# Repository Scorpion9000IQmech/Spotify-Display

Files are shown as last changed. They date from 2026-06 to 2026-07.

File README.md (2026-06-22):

## Spotify Display
---
I made a spotify display case, it does a number of things, it is recharchable by a battery module(it is connected to a TP4056 charging module with 3.3V output for the esp32), it has holes for both uploading the code as well as charging the battery

### Display
#### Startup
on startup is shows an animation of a red heart thumping, the text "Manis Music" and "by ahmed" on the screen in green, this lasts for 8 second I beleive
it switches to a loading... screen
#### Main screen
THE MAIN SCREEN shows up which has the pakistan flag on the top right
it has the artist name and track in text that cycles through rainbow colours every 1 second, and the text also has a shadow
there is a progress bar as well the minutes and second below it of how much of the song is complete
there is also a volume bar which changes by increments of 5, starting at 50 percent on startup, this can be contorlled by the volume up and down buttons(this changes the spotify volume, does not work on mobile spotify, only desktop)
the case as a whole has 5 buttons: next, play/pause, previous, Vol up, vol down
#### The Case layout
the screen is in the front of the case, the case has a lid at the back that can be latched on and off.
inside the case there is a space for the screen, screw holes to latch it on, as well as a place for the ESP32 which also has holes to latch it on with a bolt or screw, there is a space for the USB C charging module as well as the battery securing spot.
I also have spots for the keyswitches to sit securely

### Example Images
---






### wiring diagram
---


this is the final, with the space for for all componets to sit securely in the case, and for it to securely close, as well as a heart in which an led will glow, preferrably red!!!

### IM GOING TO PAY FOR THIS ALL MYSELF

## BOM

| **DISPLAYparts** | **cost USD** | **where to get from/link** | 
|---|---|---|
| 3d printer parts | 133 g(diff filaments diff cost but about 1.8 USD) | I get my filament from microless and print with my personal printer |
| Keyboard switches(better reliability) | 7 USD(pakistan local online shop/I suggest getting from another for obvious reasons) | [Daraz Pakistan](https://www.daraz.pk/products/mechanical-keyboard-switches-3-pin-rgb-hot-swappable-blue-red-brown-black-silent-tactile-switches-for-gaming-keyboard-70-million-clicks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) |
| ST7735 SPI | 4.29 USD | [Ali Express](https://ar.aliexpress.com/item/1005010340668858.html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) |
| C3 MINI LOLIN | 14.36 USD | [Ali Express](https://ar.aliexpress.com/item/1005004740051202.html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) |
| BATTERY 3.7V LiPo rechargeable | 2 for 3.9 USD each | (local) |
| TP4056 with protection(MIcro usb-c) | USD 2.32 | [Ali Express](https://ar.aliexpress.com/item/1005007355163444.html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) |
| 6 M3 screws for the screen|depends on your local source | Local bought |
| multimeter to adjust boost converter | 13 USD,(local) | - |
| **TOTAL cost(just the case and componets)** | **40 USD** | - |

# Step by step tutorial/explanation
---
1. upload the code to the esp32, and fill in the internet information, client information from spotify, and the refresh token that you can create, here(https://spotify-refresh-token-generator.netlify.app/#info)
2. solder header pins to the esp32 and the display board, solder the battery to the mt3608 charger module
3. connect the esp32 and display with dupont wires
4. connect the mt3608 to the LED/VCC from display and the 3v3 pin on esp32, this needs to be solered together into a bus, as its 3 wires for one connection, I personally soldered them all to one wire and used that wire to connect to the mt3608 VOUT+
5. use the dupont wires with pins on the other end to connect to the button pins on the esp32, solder the pin end to one end of the key, solder a normal wire with two pins to the other end, as this will be the ground
6. at this point everything is connected if youve gone by the wiring diagram, the code uploaded, and once all the ground wires are connected into one bus, and connected to mt3608 VOUT-, then the display should power on, from here it plays the animation, and displays the song playing, buttons are in the order you arranged them.

# FINAL EXAMPLE IMAGES
---
### the esp32, tp4056 and battery are shown here below all of the messy wiring


### the front showing the display, and what it is displaying


this shows the artist, song, progress of song, and the volume percent, once paused it stops the progress, volume bar changes with the press of the buttons, and it switches every refresh when a new song is played, with previous or next buttons

### the door


the door obviously has space for the two usb ports to work

### the keyswitches on top


all 6 keyswitches, play/pause on the bottom right, next middle bottom, previous is bottom left, vol down button on the top right, and vol up button on the top left, of course the orientation of these changes depending on which pin the wire connected is in each keyslot, but the upper middle button does nothing as of now, it is meant to be for an extra purpose, such as on/off, or to toggle the led which can be kept in the heart, additionallyt if put between the power bus or GND bus, it can be used to restart the display, rerunning the animation, thats what it does for me as of now, a reset button

### the esp32, tp4056 and battery meant to be used




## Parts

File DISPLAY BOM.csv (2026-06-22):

DISPLAYparts | cost USD | where to get from/link
3d printer parts | 133 g(diff filaments diff cost but about 1.8 USD) | I get my filament from microless and print with my personal printer
Keyboard switches(better reliability) | 7 USD(pakistan local online shop/I suggest getting from another for obvious reasons) | https://www.daraz.pk/products/mechanical-keyboard-switches-3-pin-rgb-hot-swappable-blue-red-brown-black-silent-tactile-switches-for-gaming-keyboard-70-million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
ST7735 SPI | 4.29 USD | https://ar.aliexpress.com/item/1005010340668858.html
C3 MINI LOLIN | 14.36 USD | https://ar.aliexpress.com/item/1005004740051202.html
BATTERY 3.7V LiPo rechargeable | 2 for 3.9 USD each | (local)
TP4056 with protection(MIcro usb-c) | USD 2.32 | https://ar.aliexpress.com/item/1005007355163444.html
6 M3 screws for the screen | depends on your local source | Local bought
multimeter to adjust boost converter | 13 USD | (local)

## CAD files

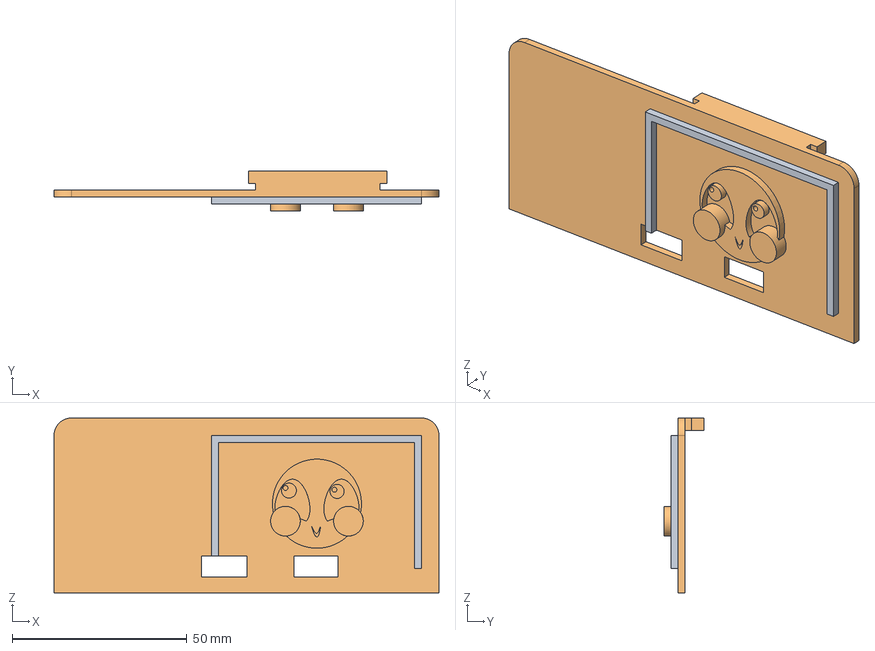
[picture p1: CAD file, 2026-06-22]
STEP files/SPOTIFY DISPLAY 3d print(redesign with keyswitches)(door).step
110.0 x 11.5 x 50.0 mm

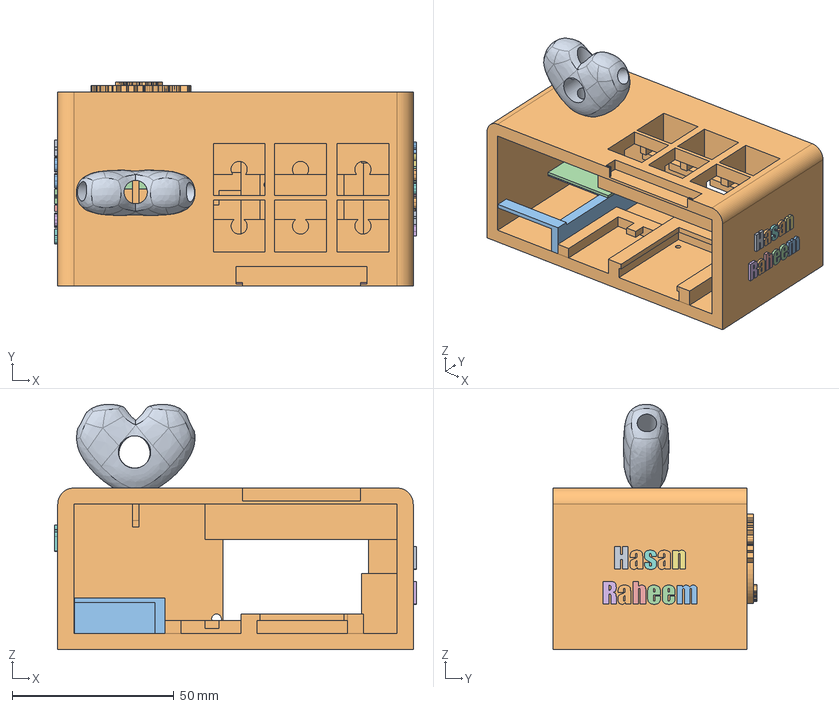
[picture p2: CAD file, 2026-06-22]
STEP files/SPOTIFY DISPLAY 3d print(redesign with keyswitches)(case).step
112.0 x 63.0 x 75.9 mm

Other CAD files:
STEP files/old design, with componets, for the sake of showing where they are placed(ignore the MT3608, it is removed as it wasnt needed).step
STL files/SPOTIFY DISPLAY 3d print(redesign with keyswitches)(case).stl
STL files/SPOTIFY DISPLAY 3d print(redesign with keyswitches)(door).stl

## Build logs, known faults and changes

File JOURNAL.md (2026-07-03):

<!--
  This journal is auto generated by Stasis.
-->

# 6/22/2026 1 PM - Soldered, everything

_Time spent: 7h_

since everythign else was settled, the code working, the keyswtiches soldered, I soldered header pins to the esp32, broke one, resoldered another esp32, used the same pins, connected the keyswtiches to new pins(soldered), as the last ones woudnt connect to the header pins

I then soldered all the GND wires together and connected that mess to the VOUT- of the battery charger module

after that I slid all of it in from the display slot, as the display sits snug in its place, perhaps with the screw holes even better, but it was the only way to get the display in, I put the battery, charger module and esp32 in their places, and then skipped on the booster module entirely as i realized i didnt NEED it, as it worked just fine at 3.3V and it would just add more unncessart wiring


I do not need more wiring, I taped up all the exposed joints as well, just in case
here is the front





here is the door to push all that messy wiring in



here is the esp32 with pinheaders



here is the charger module


the battery


and the keyswitches soldered in









# 6/16/2026 12 PM - Soldered the keyswitched to some wired, tested them out

_Time spent: 1h_

I tested out wether the buttons work, after soldering them to wires, I then tested them out on esp32 and spotify, the next, prev and play/pause button work, but my volume buttons dont actually change the volume yet so im still working on that, as for everything else, its basically done, just need to solder the board to the display, and the buttons as well as the battery





# 6/7/2026 10 AM - I printed and found some problems to redesign and print

_Time spent: 7h_

I first let it print for AGES, but now its done, first of all the front of the print didnt print its text properly cause I printed it facing down, I shall print it facing up, it might take more filament however.



 second of all the display hole is not big enough as I did not consider the yellow strip, so I will make it a tad wider, so it fits snuggly, the holes for tighetning are also SLIGHLY off, I will try to see if it needs fixing or if I can still use it as is

the heart printed fine, the area for esp32 fits perfectly as intended, as well as the battery module placement, and the heart for the LED, ALSO the key switch holes fit perfectly as well, I will however afterwards print keycaps for them, or find some, lets see



I will also fix the latch for the door as it is also kind of too fragil as well as not fitting properly due to its small size allowing it to deform easily when printing

The batterys space, is a little less than needed so ill have to make it bigger so it fits snuggly, but it is a good enough length



as for the soldering and wiring I have tested it out, but I will test the buttons while it reprints, also I will solder the display, the esp32, the battery module and the voltage booster before hand then insert it from the display hole and then fit them into their places, as the wires ar elong enough and this makes it easier to fit everything, 

However the battery will be soldered afterwards to the battery module, as it will be a bit more a pain to insert with the rest, and isnt as much of a problem as the tiny other parts, I will also solder the buttons in afterwards obviously due to how they fit I must solder them as they sit slightly outside with the wires sticking out, then insert them into the holes afterwards

That is the current plan, I will also try and use a more beautifull filament for the print, as I ordered a new prettier one, and this will turn out nice with it, though I must do some temperature testing





# 6/3/2026 11 AM - Fixed, display problems in code and fixed 3d printer

_Time spent: 7h_

I put 7 hours for convenicnec but fixing my 3d printer took days, many days, as it was needing TONS of maintenance plus i was swithcing to PETG, so i had to calibrate for that too, but its fixed now
as for the actual electronic heres my notes to myself from before as i was working on it even when it hasnt been approved!!!

while testing on the esp32 I fixed countless problems such as the esp32 not connecting to wifi, I had to change a bit so it connectsz use my own data, and I also started using vbus instead of 3.3V to power the display as the intterney wasnt connectinf otherwise to the internet

I spent alot of time makinf the texts and drawinf on screen appear the right place, not overlap and refresh properly by clearing the previous tect each loop which I made as a mistake often, everyrhinf else seems to work with the display

made my startup animation slower and the heart the proper shape cause it was upside down, along with other problems like flashing, lagging, crashing every 7 refreshes then returning

after fixing ALL of these, I started fixing the 3d printer, and now it is, the electronics including the battery modules have been tested using a breadboard, so I must now only print the case and solder the boards together with the wires, and call it a day!!!





# 4/28/2026 9 PM - I worked on the wiring diagram

_Time spent: 2h_

I worked on the wiring diagram cause I needed to make that
I made my own designs for the boards, since I coudnt find any online that werent the bare chip and trying to make the entire boards and module would be a waste of time since I only need to show how to connect the componet

here is shows all of the symbols, everything labeled gnd connects to the MT3608 booster module

The battery connects to the charging module, which conencts to the booster module which connects to the esp32 and hence the display and led, the led originally was meant to have a GPIO pin as well as a buzzer so I can make it a part of the startup animation like the passive buzzer could play a melody but I didnt have enough pins so I gave up on that idea, for now.



I also fixed my firmware to include the right pins from the esp32






# 4/25/2026 8 AM - I fixed my github and changed it into keyaswitches instead

_Time spent: 1h_

I was told the pushbuttons Id gotten were unreliable and so i instead switched them out for keyswitches and redeigned the case so it fits the keyswitches properly instead

I also changed my BOM, got the final cost, added links, I didnt calculate 3d printer part costs as that is not smthn I can accurately estimate as I use my own and even for that the diff filaments likely will have a range of prices for 1kg and hence 133 g for the case and door



I also added a place for the battery booster module to sit properly, but I coudnt add alot since i didnt wanna obstruct its wires yet also secure it



# 4/22/2026 5 PM - bettered the display

_Time spent: 2h_

WhatsApp Image 2026-04-22 at 21.19.17
I finished designing it, making a place with the heart to glow, with an led inside, I made some designs on the case, and made places for the charging module, battery, to be secure, and I also made holes to add fasteners for the screen and the esp32






# 4/22/2026 11 AM - I modified the case and slighly changed a few things like colours

_Time spent: 5h_

I made the case larger to fit the battery and the MT3608 booster(for making the 3.7V into 5V for the ESP32, as well as the TP4056 charging module to charge the recharchable battery, with s USB C port, as it is simpler for most people, phone charger I mean.

I added holes for screws or bolts to secure the screen in the holes on the screens baord and also the ESP32
I secured the TP4056 instead with the same side to side insider case as the ESP32, but added a portrusion on the inside so it doesnt go up either

For Now the MT3608 booster is on the corner next to the screen, since I must fit the battery first, to see where I can fit it, while still leaving room for wire connecitons

I spent a RIDICUOLOUSLY long time going back and forth trying to fix my code, changing libraries to one that will allow me to do what i wanna till realizing, ill wait to get an esp32 to properly find out what i need to change





# 4/21/2026 9 AM - modified the case and the program

_Time spent: 6h_



added a sliding lock for the door to the case



finished the code on the application so it used the three buttons and connects to spotify and displays it, I hope to improve it once I can use it

then being my first time, I consulted an AI on explaining the code to me, so I may add more to the spotify display, and spent a bit learning that, how it works.


I used these switches in my design, so I designed horizontal holders for the switches

I changed the switches in the guide to this so i could design keys around this

I changed alot of the code so that it has a startup animation of a thumping heart the text "Manis Music"
and "by ahmed" as well as loading screen

in the main loop I added a progress bar with the time underneath it written down as well as a volume bar percentage and the buttons needed to change it

I added space for SIX buttons so one of them can be an on and off button, oh yes, I added a battery as well, as to be honest, I got insanely fired up when I decided to direct this effort as a gift for my friend Mani

which is why I made the custom animation and the rest of the UI, as well as a battery so it becomes portable





# 4/18/2026 12 PM - I worked on the spotify display

_Time spent: 1h_

I created the app for the spotify display on spotify developers

then I setup the wifi connection using the guide
Though I strugggled to understand it, I used the code shown on the guide, but I beleive that is not enough? as it is a extremely simplified version





Hence before I complete this, I will take some time to understand the code so I can make a real differrence on  how I wish to customise the code to my desire, before I proceed with it




# 4/16/2026 4 PM - I created the display and the base of it

_Time spent: 1h_



I made the base design of the box



this is of course before I have done any of my own designing as I wish to




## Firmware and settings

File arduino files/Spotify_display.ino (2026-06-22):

#include <SpotifyArduinoCert.h>
#include <WiFiClientSecure.h>

#include <Arduino.h>
#include <ArduinoJson.h>
#include <Adafruit_GFX.h>
#include <Adafruit_ST7735.h>
#include <WiFi.h>
#include <SpotifyArduino.h>
#include <SPI.h>

#define TFT_CS 4
#define TFT_RST 2
#define TFT_DC 3
#define TFT_SCLK 6
#define TFT_MOSI 7
#define BTN_NEXT 0
#define BTN_PREV 10
#define BTN_PLAY 1
#define BTN_VOL_UP 8
#define BTN_VOL_DOWN 5

const char* SSID = "example";
const char* PASSWORD = "example";
const char* CLIENT_ID = "example";
const char* CLIENT_SECRET = "example";

unsigned long lastSpotifyUpdate = 0;
const int spotifyInterval = 4000;

unsigned long lastLocalUpdate = 0;
int localProgress = 0;
bool isPlaying = false;

String lastArtist;  
String lastTrackname;
String currentArtist;
String currentTrackname;

int progress = 0;
int duration = 1;
int currentVolume = 50; 

int rainbowColors[] = {ST77XX_CYAN, ST77XX_MAGENTA, ST77XX_YELLOW, ST77XX_GREEN, 0xFD20, 0xF81F, 0x07FF};
int animationStep = 0;

WiFiClientSecure spotifyClient;

SpotifyArduino MANI(spotifyClient, CLIENT_ID, CLIENT_SECRET);
Adafruit_ST7735 ROSE = Adafruit_ST7735(TFT_CS, TFT_DC, TFT_RST);

String truncateText(String text, int maxLength) {
    if (text.length() > maxLength) {
        return text.substring(0, maxLength) + "...";
    }
    return text;
}


void drawProgressBar(int progress, int duration) {
    int barWidth = 120;
    int barHeight = 8;
    int x = 10;
    int y = 60;
    ROSE.fillRect(x, y, barWidth, barHeight, ST77XX_BLACK);
    int filled = (progress * barWidth) / duration;

    ROSE.drawRect(x, y, barWidth, barHeight, ST77XX_WHITE);
    ROSE.fillRect(x, y, filled, barHeight, ST77XX_RED);
}

void drawVolumeBar(int volume) {
    int barWidth = 120;
    int barHeight = 6;
    int x = 10;
    int y = 95;
    ROSE.fillRect(x, y, barWidth, barHeight, ST77XX_BLACK);
    int filled = (volume * barWidth) / 100;

    ROSE.drawRect(x, y, barWidth, barHeight, ST77XX_WHITE);
    ROSE.fillRect(x, y, filled, barHeight, ST77XX_GREEN);
}

String animateCapitalLetters(String text, int step) {
    String result = "";
    for (int i = 0; i < text.length(); i++) {
        if (i <= step % (text.length() + 1)) {
            // makes letter capital
            result += (char)toupper(text[i]);
        } else {
            // keep original case
            result += text[i];
        }
    }
    return result;
}

void drawTimeCounter(int progress, int duration) {
    // Calculate minutes and seconds for current position
    int currentSeconds = progress / 1000;
    int currentMinutes = currentSeconds / 60;
    int currentRemainingSeconds = currentSeconds % 60;
    
    // Calculate total song length
    int totalSeconds = duration / 1000;
    int totalMinutes = totalSeconds / 60;
    int totalRemainingSeconds = totalSeconds % 60;
    
    // Format as "0*:** / 0*:**"
    char timeText[30];
    sprintf(timeText, "%02d:%02d / %02d:%02d", 
            currentMinutes, currentRemainingSeconds,
            totalMinutes, totalRemainingSeconds);
    
    // display time below progress bar
    ROSE.setTextSize(1);
    ROSE.setTextColor(ST77XX_RED);
    ROSE.fillRect(10, 70, 140, 20, ST77XX_BLACK);
    ROSE.setCursor(10, 72);
    ROSE.print(timeText);
}

void drawVolumePercent(int volume) {
    char volumeText[12];
    sprintf(volumeText, "Vol: %d%%", volume);

    ROSE.fillRect(10, 108, 80, 14, ST77XX_BLACK);
    ROSE.setTextSize(1);
    ROSE.setTextColor(0xFFE0);
    ROSE.setCursor(10, 110);
    ROSE.print(volumeText);
}

void drawPakistanFlag() {

    int x = 130;
    int y = 2;
    int w = 25;
    int h = 16;

    // LEFT WHITE STRIPE
    ROSE.fillRect(x, y, 5, h, ST77XX_WHITE);

    // RIGHT GREEN PART
    ROSE.fillRect(x + 5, y, w - 5, h, 0x07E0);

    // MOON
    ROSE.fillCircle(x + 14, y + 8, 4, ST77XX_WHITE);
    ROSE.fillCircle(x + 15, y + 8, 3, 0x07E0);

    // STAR (simple dot version for reliability)
    ROSE.fillRect(x + 18, y + 6, 2, 2, ST77XX_WHITE);
}

void currentlyPlayingCallback(CurrentlyPlaying currentlyPlaying) {

    if (currentlyPlaying.trackName == "") {
        isPlaying = false;
        return;
    }

    isPlaying = currentlyPlaying.isPlaying;

    currentArtist = currentlyPlaying.artists[0].artistName;
    currentTrackname = currentlyPlaying.trackName;

    duration = currentlyPlaying.durationMs;

    // ALWAYS sync progress from Spotify
    progress = currentlyPlaying.progressMs;

    // smooth local timer continues from spotify value
    localProgress = progress;

    lastLocalUpdate = millis();

    static String prevTrack = "";

    if (currentTrackname != prevTrack) {

        Serial.println("NEW SONG: " + currentTrackname);

        animationStep = 0;

        prevTrack = currentTrackname;
    }
}

void setup() {
    Serial.begin(115200);
    Serial.setDebugOutput(true);

    pinMode(BTN_NEXT, INPUT_PULLUP);
    pinMode(BTN_PREV, INPUT_PULLUP);
    pinMode(BTN_PLAY, INPUT_PULLUP);
    pinMode(BTN_VOL_UP, INPUT_PULLUP);
    pinMode(BTN_VOL_DOWN, INPUT_PULLUP);

    SPI.begin(TFT_SCLK, -1, TFT_MOSI, TFT_CS);

    ROSE.initR(INITR_BLACKTAB); // the type of screen
    Serial.println("2");
    ROSE.setRotation(1); // this makes the screen landscape! remove this line for portrait
    Serial.println("TFT Initialized!");
    // STARTUP ANIMATION WITH THUMPING HEART
    ROSE.fillScreen(ST77XX_BLACK);

    // heart that thumps 8 times
    for (int thump = 0; thump < 8; thump++) {
        ROSE.fillScreen(ST77XX_BLACK);  // clear screen each thump
    
        // heart gets bigger and smaller (thumping effect)
        int heartSize;
        if (thump % 2 == 0) {
            heartSize = 22;  // normal size on even thumps
        } else {
            heartSize = 28;  // bigger size on odd thumps 
        }
    
        // Draw the heart in center of screen
        int centerX = 80;
        int centerY = 50;   
    
        
        ROSE.fillCircle(centerX - heartSize/2, centerY, heartSize/2, ST77XX_RED);
        ROSE.fillCircle(centerX + heartSize/2, centerY, heartSize/2, ST77XX_RED);
    
        
        for (int y = 0; y <= heartSize; y++) {

            // make the heart get narrower toward bottom
            int width = (heartSize*2) - (y*2);

            ROSE.drawLine(
                centerX - width/2,
                centerY + y + 4,

                centerX + width/2,
                centerY + y + 4,

                ST77XX_RED
            );
        }
    
        ROSE.setTextColor(0xF81F);
        ROSE.setTextSize(2);
        ROSE.setCursor(25, 85);
        ROSE.print("Manis Music");
    
        ROSE.setTextSize(1);
        ROSE.setCursor(55, 105);
        ROSE.print("By The Man");
    
        delay(800);
    }

    // show final heart with loading text
    ROSE.fillScreen(ST77XX_BLACK);
    // draw final heart at normal size
    int centerX = 80;
    int centerY = 50;
    ROSE.fillCircle(centerX - 10, centerY, 10, ST77XX_RED);
    ROSE.fillCircle(centerX + 10, centerY, 10, ST77XX_RED);
        for (int y = 0; y <= 20; y++) {

            // starts wide, shrinks downward
            int width = 40 - (y * 2);

            ROSE.drawLine(
                centerX - width/2,
                centerY + y + 4,
               centerX + width/2,
                centerY + y + 4,
                ST77XX_RED
            );
        }

    ROSE.setTextColor(0xF81F);
    ROSE.setTextSize(2);
    ROSE.setCursor(20, 85);
    ROSE.print("Manis Music");
    ROSE.setTextSize(1);
    ROSE.setCursor(55, 105);
    ROSE.print("By The Man");

    delay(5000);
    ROSE.fillScreen(ST77XX_BLACK);
    ROSE.setCursor(20, 50);
    ROSE.setTextColor(ST77XX_GREEN);
    ROSE.setTextSize(2);
    ROSE.print("Loading...");
    delay(1500);
    ROSE.fillScreen(ST77XX_BLACK);
    // END OF STARTUP ANIMATION

    WiFi.persistent(false);
    WiFi.mode(WIFI_OFF);
    delay(1000);

    WiFi.mode(WIFI_STA);
    WiFi.setSleep(false);
    delay(500);

    Serial.print("Connecting to ");
    Serial.println(SSID);

    WiFi.begin(SSID, PASSWORD);

    unsigned long startAttempt = millis();

        while (WiFi.status() != WL_CONNECTED && millis() - startAttempt < 45000) {
        delay(500);
        Serial.print(".");
    }

    Serial.println();

    if (WiFi.status() == WL_CONNECTED) {
        Serial.println("Connected!");
        Serial.print("IP: ");
        Serial.println(WiFi.localIP());
        Serial.print("RSSI: ");
        Serial.println(WiFi.RSSI());
    } else {
        Serial.print("WiFi failed. Status: ");
        Serial.println(WiFi.status());

        ROSE.fillScreen(ST77XX_BLACK);
        ROSE.setCursor(10, 50);
        ROSE.setTextColor(ST77XX_RED);
        ROSE.setTextSize(1);
        ROSE.print("WiFi failed: ");
        ROSE.print(WiFi.status());

        return;
    }

    spotifyClient.setInsecure();
    spotifyClient.setTimeout(15000);
    delay(1000);
    IPAddress ip;

    if (WiFi.hostByName("accounts.spotify.com", ip)) {
        Serial.print("Spotify IP: ");
        Serial.println(ip);
    }
    else {
    Serial.println("DNS FAILED");
    }

    MANI.setRefreshToken("refresh token");
    MANI.refreshAccessToken();

    MANI.getCurrentlyPlaying(currentlyPlayingCallback);

    ROSE.setCursor(0,0); // make the cursor at the top left
    ROSE.write(WiFi.localIP().toString().c_str()); // print out IP on the screen
    ROSE.fillScreen(ST77XX_BLACK);

}

void loop()
{
    static int colorCycle = 0;  

    if (digitalRead(BTN_NEXT) == LOW) {
        Serial.println("NEXT button pressed");

        bool ok = MANI.nextTrack();
        Serial.print("nextTrack result: ");
        Serial.println(ok);

        delay(700);
        MANI.getCurrentlyPlaying(currentlyPlayingCallback);
        lastSpotifyUpdate = millis();
    }

    if (digitalRead(BTN_PREV) == LOW) {
        Serial.println("PREV button pressed");

        bool ok = MANI.previousTrack();
        Serial.print("previousTrack result: ");
        Serial.println(ok);

        delay(700);
        MANI.getCurrentlyPlaying(currentlyPlayingCallback);
        lastSpotifyUpdate = millis();
    }

    if (digitalRead(BTN_PLAY) == LOW) {
        Serial.println("PLAY button pressed");

        bool ok;

        if (isPlaying) {
            ok = MANI.pause();
            Serial.print("pause result: ");
            Serial.println(ok);
            if (ok) isPlaying = false;
        } else {
                ok = MANI.play();
                Serial.print("play result: ");
                Serial.println(ok);
                if (ok) isPlaying = true;
        }

        delay(700);
        MANI.getCurrentlyPlaying(currentlyPlayingCallback);
        lastSpotifyUpdate = millis();
    }

    if (digitalRead(BTN_VOL_UP) == LOW) {
        Serial.println("VOL UP button pressed");

        currentVolume += 5;
        if (currentVolume > 100) currentVolume = 100;

        drawVolumeBar(currentVolume);
        drawVolumePercent(currentVolume);

        bool ok = MANI.setVolume(currentVolume);
        Serial.print("setVolume up result: ");
        Serial.println(ok);
        Serial.print("requested volume: ");
        Serial.println(currentVolume);

        delay(700);
    }

    if (digitalRead(BTN_VOL_DOWN) == LOW) {
        Serial.println("VOL DOWN button pressed");

        currentVolume -= 5;
        if (currentVolume < 0) currentVolume = 0;

        drawVolumeBar(currentVolume);
        drawVolumePercent(currentVolume);

        bool ok = MANI.setVolume(currentVolume);
        Serial.print("setVolume down result: ");
        Serial.println(ok);
        Serial.print("requested volume: ");
        Serial.println(currentVolume);

        delay(700);
    }

   if (WiFi.status() != WL_CONNECTED) {
        isPlaying = false;
    }

    if (millis() - lastSpotifyUpdate > spotifyInterval) {

        if (WiFi.status() == WL_CONNECTED) {

            bool ok = MANI.getCurrentlyPlaying(currentlyPlayingCallback);

            if (!ok) {
                Serial.println("Spotify fetch failed");
            }

        }

        lastSpotifyUpdate = millis();
    }

    if (isPlaying) {

        unsigned long now = millis();

        localProgress += (now - lastLocalUpdate);
        lastLocalUpdate = now;

        if (localProgress > duration) {
            localProgress = duration;
        }

        progress = localProgress;
    }

    ROSE.fillRect(0, 0, 120, 30, ST77XX_BLACK);   // artist area only
    ROSE.fillRect(0, 30, 160, 25, ST77XX_BLACK);  // track area

    String animatedArtist = animateCapitalLetters(currentArtist, animationStep);
    String animatedTrack = animateCapitalLetters(currentTrackname, animationStep);

    drawProgressBar(localProgress, duration);
    drawTimeCounter(localProgress, duration);
    drawVolumeBar(currentVolume);  
    drawVolumePercent(currentVolume);
    drawPakistanFlag();

    if (lastArtist != currentArtist && currentArtist != "Something went wrong" && !currentArtist.isEmpty()) {
        lastArtist = currentArtist;
        Serial.println("Artist: " + lastArtist);
        animationStep = 0;  // reset animation when song changes
    }
    // Draw shadow 
    ROSE.setCursor(12, 12);
    ROSE.setTextColor(0x1082); 
    ROSE.write(animatedArtist.c_str());
    // draws the main text
    ROSE.setCursor(10, 10);
    ROSE.setTextColor(rainbowColors[colorCycle % 7]);
    ROSE.write(animatedArtist.c_str());

    if (lastTrackname != currentTrackname && currentTrackname != "Something went wrong" && currentTrackname != "null") {
        lastTrackname = currentTrackname;
        Serial.println("Track: " + lastTrackname);
        animationStep = 0;  // reset animation when song changes
    }
    // Draw shadow
    ROSE.setCursor(12, 42);
    ROSE.setTextColor(0x1082);
    ROSE.write(animatedTrack.c_str());
    // Draw main text
    ROSE.setCursor(10, 40);
    ROSE.setTextColor(rainbowColors[colorCycle % 7]);
    ROSE.write(animatedTrack.c_str());
    animationStep++;  // move to next letter    
    colorCycle++;

    delay(30);
}

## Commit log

2026-04-24 Update DISPLAY BOM.csv
    [DISPLAY BOM.csv]
2026-04-28 Rename Spotify Display.kicad_sch to Spotify Display connections for componets.kicad_sch
    [Spotify Display connections for componets.kicad_sch]
2026-06-22 Rename SPOTIFY DISPLAY 3d print(redesign with keyswitches).step to old design, with componets, for the sake of showing where they are placed(ignore the MT3608, it is removed as it wasnt needed).step
    [SPOTIFY DISPLAY 3d print(redesign with keyswitches).step, old design, with componets, for the sake of showing where they are placed(ignore the MT3608, it is re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]
